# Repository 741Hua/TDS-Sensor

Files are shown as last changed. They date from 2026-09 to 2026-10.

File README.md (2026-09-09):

# TDS-Sensor
The industrial Total Dissolved Solids (TDS) sensor market currently sells sensors as a two part solution: an Electrical Conductivity (EC) sensor probe and a separate box with the digitization hardware. Introducing, an all-in-one enclosure, plug and play, industrial TDS sensor intended for use in food &amp; beverage manufacturing facilities.

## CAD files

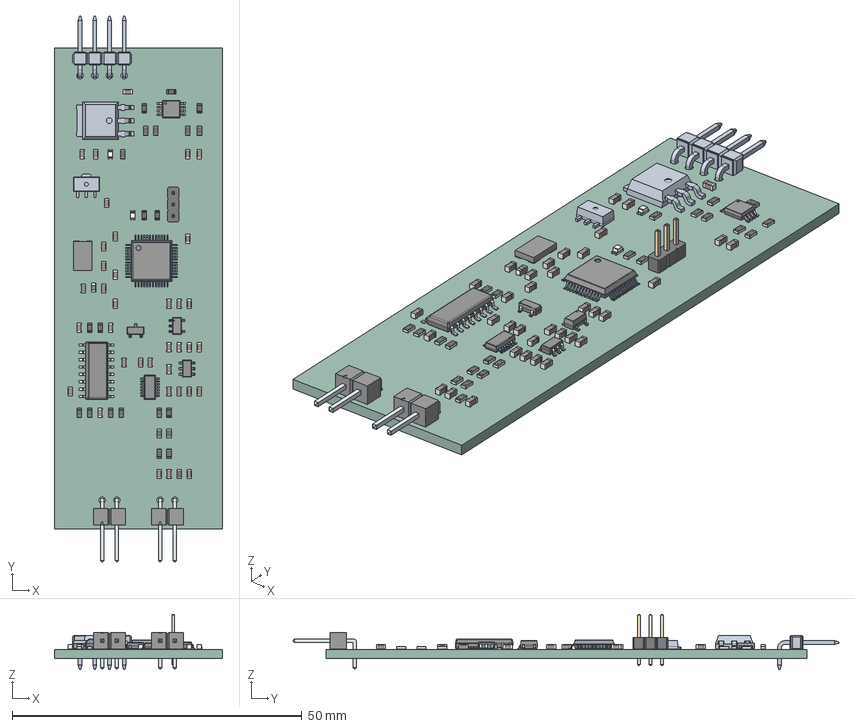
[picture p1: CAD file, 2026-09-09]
Hardware/TDS_Sensor.step
29.0 x 94.2 x 9.53 mm
R_0603_1608Metric x 23
C_0603_1608Metric x 36
PinHeader_1x03_P2.00mm_Vertical
TDS_Sensor 1.18.1
LTST-C190GKT x 2
Pins
BODY-SO
LEAD-SO x 16
PIN1-ID
PinsArrayL
PinsArrayR
LeadsArray x 2
PinsArrayLR x 2
PinsArrayTB
BAT54_R1_00001
BLM18BD121SH1D
BODY-TSSOP
LEAD-TSSOP x 14
TDS_Sensor 1.61.1
BODY-SOT
LEAD-SOT x 6
TDS_Sensor_PCB

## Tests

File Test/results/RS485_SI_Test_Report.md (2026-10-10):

# Hardware Bring‑Up Test Report 
**Document ID:** TDS-DTR-002 
**Revision:** 1.0  
**Author:** Jairo Huaylinos  
**Date:** 2026‑10-10

---

# Table of Contents
1. Introduction  
2. Unit Under Test  
3. Equipment Required  
4. Test Plan Overview  
5. Test Procedures 
6. References 

---

# 1. Introduction
This document defines the Modbus over RS-485 half duplex Signal Integrity (SI) testing for the All-In-One STM32‑based Total Dissolved Solids (TDS) sensor PCB. It outlines the Unit Under Test (UUT), required test equipment, describes the test stages, and provides step‑by‑step procedures with clear success criteria.

Goal: Verify reliable Modbus RTU communication over RS‑485 half‑duplex on the prototype PCB.
Scope: Protocol‑level timing and error‑free communication. Along with basic RS‑485 electrical sanity checks.

Regulatory and formal RS‑485 electrical and commercial industrial compliance (TIA‑485, FCC Part 15, UL 61010‑1, IEC 61326‑1) are out of scope for this prototype phase. Furthermore, the TIA‑485‑A standard does not specify rise time, fall time, or jitter requirements for RS‑485 drivers.

---

# 2. Unit Under Test (UUT)

The UUT is a custom STM32‑based TDS sensor PCB, serial number 2, paired with an electrical conductivity (EC) sensor probe. The board uses an STM32F103C8T6 microcontroller with a user LED on PC13 and includes an onboard RS‑485 transceiver (PN MAX485CUA+T) for the electrical interface for Modbus protocol communication. The analog front end is an AC‑excitation EC measurement circuit designed to output a DC voltage based on the conductivity through the external EC probe. Power is supplied through a 12 V input and regulated down to 5 V, 3.3 V, 3 V, and −3 V rails.

---

# 3. Equipment Required

| Name | Part Number | Description |
|---|---|---|
| ST‑Link Programmer | ST‑LINK/V2 | SWD programmer/debugger with 3.3 V supply |
| Personal Computer | N/A | Any Desktop PC or laptop |
| 12V Power Supply | N/A | 12 V DC Wall Adapter with modified leads |
| Oscilloscope | SDS 1202X-E | Siglent 200 MHz 1Gsa/s Digital Storage Oscilloscope |
| Digital Multimeter | DM6000AR | AstroAI True-RMS DMM, 6000 Counts |
| Blink Firmware | N/A | Toggles PC13 LED for basic MCU verification |
| Modbus Dummy Slave Firmware | N/A | Sends fixed Modbus FC04 response frames for RS‑485 validation |
| ADC + Modbus Firmware | N/A | Reads ADC and reports voltage via Modbus |
| ModbusTool SW |  N/A | Modbus Master tool to poll UUT. https://github.com/ClassicDIY/ModbusTool.git |
| USB - RS485 Converter | N/A | CERRXIAN 1FT RS485 to USB Terminal Converter Serial Port Cable |

---

# 4. Test Plan Overview

The RS485 Signal Integrity Test Plan covers 3 baud rates: 1200, 9600, 19200 Bd. For each of those rates, the following are verified:
- Successful transmission and reception of Modbus RTU messages.
- Device UART message frames are transmitted with less than 1.5 character times spacing. 1 character is defined as one full UART frame. 1 character is 11 bits (1 start bit, 8 bits for data, 1 parity bit, and 1 stop bit)
- Device transmission baud rate accuracy is within 1%.
- RS-485 logic voltage level differential between A and B should be between +-1.5V to +-6V

Each stage includes structured procedures with defined success criteria.

Out of scope:
- Recepetion baud rate tolerance of up to 2%. -> do not have tools to test this. this is more of a software capability.
- Response to both unicast and broadcast messages.
- Even Parity testing is not included since test plan is hardware centric, not protocol centric.

---

# 5. Test Procedures

---

## 5.1 ST‑Link Power‑Up Procedure

<p align="center">
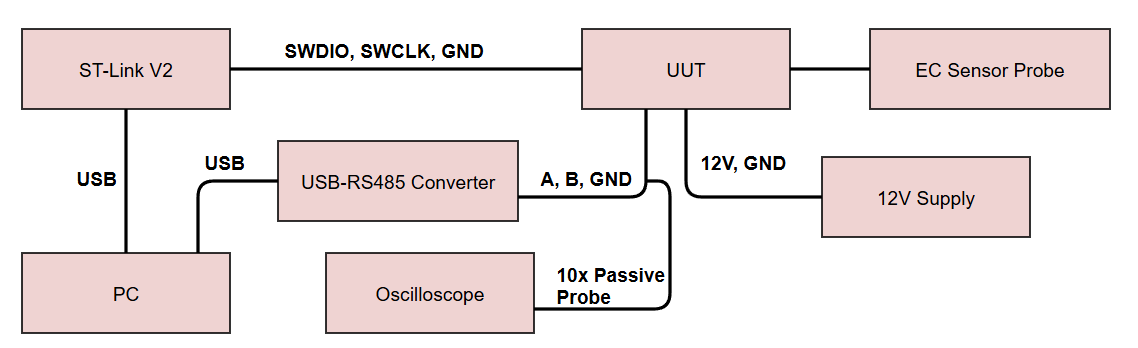
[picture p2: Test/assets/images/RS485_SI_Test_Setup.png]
Test Setup
  
  <br>
  <em>Figure 1: RS485 SI Test Setup</em>
</p>

<p>&nbsp;</p>

| Step # | Description | Success Criteria | P/F |
|---|---|---|-----|
| 1 | Connect the oscilloscope probes to the RS485 A (CH1) and B (CH2) output wires on the TDS sensor board | Probe is connected to A and B lines with appropriate ground reference | ✅ |
| 2 | Connect ST-Link SWCLK, SWDIO, and GND pins to the UUT on connector J2. Disconnect 3.3V pin | Board remains unpowered until 12V is applied | ✅ |
| 3 | Connect ST-Link SWCLK, SWDIO, and GND pins to the UUT on connector J2. Do not conect the 3.3V pin | Board remains unpowered until 12V is applied | ✅ |
| 4 | Connect the USB-RS485 Converter A, B, and GND rails to the UUT on connector J4. Connect the USB interface end to your PC. | Board remains unpowered until 12V is applied | ✅ |
| 5 | Flash Modbus RTU slave driver code with a 9600 baud rate (use a release build, not debug build). | Release build is successfully flashed to the board successfully with no errors | ✅ |
| 6 | Open the Modbus Master SW tool on your PC. Connect to the corresponding COM port with Baud=9600, Parity = None, Data Bits = 8, and Stop Bits = 1, Slave ID = 1. These settings should match you UART settings on the UUT's MCU. | Log shows "Connected using RTU to COMX", Stable connection. | ✅ |
| 7 | Select "read input register" in functions and set Poll to 4000 and check the box to activate polling. Set Start Address to 0. Set Size to 1. Click Apply button| Log shows "Read succeeded: Function Code: 4." | ✅ |
| 8 | Set oscilloscope to 2V/Div, 1ms/Div, trigger level to 2.5V, rising edge on CH2. Setup for normal capture, with 12ms holdoff. Press Stop on the second frame to display. | Oscilloscope captures modbus response frame from the TDS module and not master transmit frame. Verify bits.| ✅ |
| 9 | Measure the spacing between UART frames (10-bit Modbus Characters) | spacing between character frames are less than 1.5 characters long | ✅ |
| 10 | Measure baud rate | Measured Baud Rate is between 9504 and 9696 | ✅<sup>1</sup> |
| 11 | Measure the RS-485 voltage levels | voltage driver differential should be between +-1.5V to +-6V | ✅<sup>1</sup> |
| 12 | Measure the common mode voltage | Common Mode Voltage between -7V to +12V | ✅<sup>1</sup> |
| 13 | Flash Modbus RTU slave driver code with a 19200 baud rate (use a release build, not debug build). | Release build is successfully flashed to the board successfully with no errors | ✅ |
| 14 | Open the Modbus Master SW tool on your PC. Connect to the corresponding COM port with Baud=19200, Parity = None, Data Bits = 8, and Stop Bits = 1, Slave ID = 1. These settings should match you UART settings on the UUT's MCU. | Log shows "Connected using RTU to COMX", Stable connection. | ✅ |
| 15 | Select "read input register" in functions and set Poll to 1000 and check the box to activate polling. Set Start Address to 0. Set Size to 1. Click Apply button| Log shows "Read succeeded: Function Code: 4." | ✅ |
| 16 | Set oscilloscope to 2V/Div, 500us/Div, trigger level to 2.5V, rising edge on CH2. Setup for normal capture, with 8ms holdoff. Press Stop on the second frame to display. | Oscilloscope captures modbus response frame from the TDS module and not master transmit frame. Verify bits.| ✅ |
| 17 | Measure the spacing between UART frames (10-bit Modbus Characters) | spacing between character frames are less than 1.5 characters long | ✅ |
| 18 | Measure baud rate | Measured Baud Rate is between 19008 and 19392 | ✅<sup>1</sup> |
| 19 | Measure the RS-485 voltage levels | voltage driver differential should be between +-1.5V to +-6V | ✅<sup>1</sup> |
| 20 | Measure the common mode voltage | Common Mode Voltage between -7V to +12V | ✅<sup>1</sup> |
| 21 | Flash Modbus RTU slave driver code with a 1200 baud rate (use a release build, not debug build). | Release build is successfully flashed to the board successfully with no errors | ✅ |
| 22 | Open the Modbus Master SW tool on your PC. Connect to the corresponding COM port with Baud=1200, Parity = None, Data Bits = 8, and Stop Bits = 1, Slave ID = 1. These settings should match you UART settings on the UUT's MCU. | Log shows "Connected using RTU to COMX", Stable connection. | ✅ |
| 23 | Select "read input register" in functions and set Poll to 1000 and check the box to activate polling. Set Start Address to 0. Set Size to 1. Click Apply button| Log shows "Read succeeded: Function Code: 4." | ✅ |
| 24 | Set oscilloscope to 2V/Div, 5ms/Div, trigger level to 2.5V, rising edge on CH2. Setup for normal capture, with 70ms holdoff. Press Stop on the second frame to display. | Oscilloscope captures modbus response frame from the TDS module and not master transmit frame. Verify bits.| ✅ |
| 25 | Measure the spacing between UART frames (10-bit Modbus Characters) | spacing between character frames are less than 1.5 characters long | ✅ |
| 26 | Measure baud rate | Measured Baud Rate is between 1188 and 1212 | ✅<sup>1</sup> |
| 27 | Measure the RS-485 voltage levels | voltage driver differential should be between +-1.5V to +-6V | ✅<sup>1</sup> |
| 28 | Measure the common mode voltage | Common Mode Voltage between -7V to +12V | ✅<sup>1</sup> |

### Notes

1. The measured baud rate, A-B differential voltage, and common mode voltage values are recorded below for each tested communication rate.

| Baud Rate | Measured Baud Rate | A-B Voltage Differential | Common Mode Voltage |
|---|---|---|---|
| 9600 | 9615 | ~2.78V | ~2.14V |
| 19200 | 19160 | ~2.76V | ~2.145V |
| 1200 | 1198 | ~2.78V | ~2.145 |

<p align="center">
  <em>Figure 2: Measured Values from Test</em>
</p>

---

# 6. References

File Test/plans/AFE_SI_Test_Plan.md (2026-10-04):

# Hardware Bring‑Up Test Plan & Procedures  
**Document ID:** TDS-DTP-004 
**Revision:** 1.0  
**Author:** Jairo Huaylinos  
**Date:** 2026‑10-04

---

# Table of Contents
1. Introduction  
2. Unit Under Test  
3. Equipment Required  
4. Test Plan Overview  
5. Test Procedures  
6. References

---

# 1. Introduction
This document defines the Modbus over RS-485 half duplex Signal Integrity (SI) testing for the All-In-One STM32‑based Total Dissolved Solids (TDS) sensor PCB. It outlines the Unit Under Test (UUT), required test equipment, describes the test stages, and provides step‑by‑step procedures with clear success criteria.

Goal: Verify reliable Modbus RTU communication over RS‑485 half‑duplex on the prototype PCB.
Scope: Protocol‑level timing and error‑free communication. Along with basic RS‑485 electrical sanity checks.

Regulatory and formal RS‑485 electrical and commercial industrial compliance (TIA‑485, FCC Part 15, UL 61010‑1, IEC 61326‑1) are out of scope for this prototype phase. Furthermore, the TIA‑485‑A standard does not specify rise time, fall time, or jitter requirements for RS‑485 drivers.

---

# 2. Unit Under Test (UUT)

The UUT is a custom STM32‑based TDS sensor PCB, serial number 2, paired with an electrical conductivity (EC) sensor probe. The board uses an STM32F103C8T6 microcontroller with a user LED on PC13 and includes an onboard RS‑485 transceiver (PN MAX485CUA+T) for the electrical interface for Modbus protocol communication. The analog front end is an AC‑excitation EC measurement circuit designed to output a DC voltage based on the conductivity through the external EC probe. Power is supplied through a 12 V input and regulated down to 5 V, 3.3 V, 3 V, and −3 V rails.

---

# 3. Equipment Required

| Name | Part Number | Description |
|---|---|---|
|  |  |  |
|  |  |  |
|  |  |  |
|  |  |  |
|  |  |  |
|  |  |  |
|  |  |  |
|  |  |  |
|  |  |  |
|  |  |  |

---

# 4. Test Plan Overview

The hardware bring‑up consists of four main stages:

1. **Packet transmission**  
   Verifies MCU boot, clock operation, GPIO functionality, and basic power behavior using the debugger’s 3.3 V supply.

2. **Signal Rise & Fall Times**  
   The manufacturer for the MAX485CUA+T characterizes drive rise and fall times (t<sub>R</sub>, t<sub>F</sub>) as (MIN: 3ns, TYP: 15ns, MAX: 40ns) and maximum data rate f<sub>MAX</sub> as 2.5 Mbps.

Each stage includes structured procedures with defined success criteria.

Modbus communication at different baud rates. Capture log. Use representative cable lengths.

Notes for what the test should include:
   - that the device responds to both broadcast and unicast requests from the master. (Using both Even parity (required) and no parity (recommended))
   - 3.5 character spacing betweem message frames
   - try sending modbbus frames at the maximum size of 256 bytes
   - slave transmit messsage frame shoud have less than 1.5 char time spacing between 2 characters. Verify this.
   - Does my modbus slave driver code include interrupts for t1.5 and t3.5? does it monitor this? Consequently these two timers must be strictly respected when the baud rate is equal or lower than 19200 Bps
   - Typical buad rate for RS485 is 9600. 9600 bps and 19.2 Kbps are required. Must test these 2 baud rates, also test a lower baud rate of 1200. There is no minimum but this is the typical minimum baud rate in modern systems.
   - Transmit baud rate accuracy must be within 1%. Reception baud rate tolerance: must accept up to 2% error. Not sure how you'd test the reception tolerance. Where does this 1% requirement come?

Ok so test goals (hardware centric only)
- Device can recieve and transmit at 9600 bps, 19200 bps, and 1200 bps.
- Device RTU message frames must be transmitted with less than 1.5 character times spacing.
- Device transmission baud rate accuracy is within 1%.
- RS-485 voltage levels are correct.
- Less than 200mV magnitude difference between RS485 A-B vs B-A signal.

Even parity testing is not necessary here, goal is hardware centric.

1.5 character spacing: 1 character is defined as one full UART frame. 1 character is 11 bits (1 start bit, 8 bits for data, 1 parity bit, and 1 stop bit).

Out of scope:
- Recepetion baud rate tolerance of up to 2%. -> do not have tools to test this. this is more of a software capability.
- Response to both unicast and broadcast messages.
- 

---

# 5. Test Procedures

---

## 5.1 ST‑Link Power‑Up Procedure

<p align="center">
  Test Setup
  <br>
  <em>Figure 1: RS485 SI Test Setup</em>
</p>

<p>&nbsp;</p>

| Step # | Description | Success Criteria | P/F |
|---|---|---|-----|
| 1 |  |  |  |
| 2 |  |  |  |
| 3 |  |  |  |
| 4 |  |  |  |
| 5 |  |  |  |
| 6 |  |  |  |
| 7 |  |  |  |
| 8 |  |  |  |
| 9 |  |  |  |
| 10 |  |  |  |
| 11 |  |  |  |
| 12 |  |  |  |
| 13 |  |  |  |
| 14 |  |  |  |
| 15 |  |  |  |
| 16 |  |  |  |
| 17 |  |  |  |
| 18 |  |  |  |
| 19 |  |  |  |
| 20 |  |  |  |
| 21 |  |  |  |
| 22 |  |  |  |
| 23 |  |  |  |
| 24 |  |  |  |
| 25 |  |  |  |
| 26 |  |  |  |
| 27 |  |  |  |
| 28 |  |  |  |

### Notes

---

## 5.4 Analog Front End + ADC Verification Procedure

<p align="center">
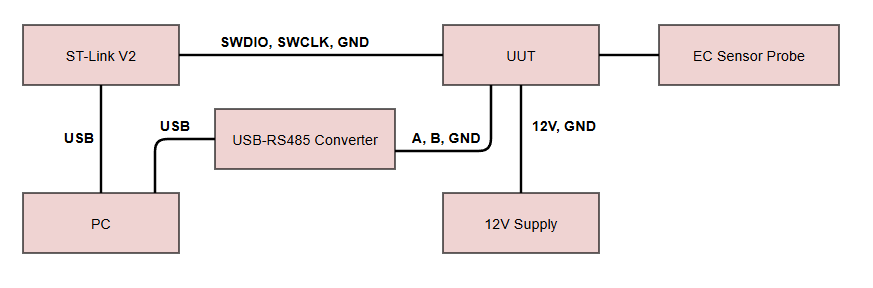
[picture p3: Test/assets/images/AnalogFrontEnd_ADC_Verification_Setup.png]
Test Setup
  
  <br>
  <em>Figure 4: Analog Front End + ADC Verification Test Setup</em>
</p>

<p>&nbsp;</p>

| Step # | Description | Success Criteria | P/F |
|---|---|---|-----|
| 1 |  |  |  |
| 2 |  |  |  |
| 3 |  |  |  |
| 4 |  |  |  |
| 5 |  |  |  |
| 6 |  |  |  |
| 7 |  |  |  |
| 8 |  |  |  |
| 9 |  |  |  |
| 10 |  |  |  |
| 11 |  |  |  |
| 12 |  |  |  |

### Notes

---

# 6. References

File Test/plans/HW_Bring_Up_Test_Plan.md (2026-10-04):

# Hardware Bring‑Up Test Plan & Procedures  
**Document ID:** TDS-DTP-001
**Revision:** 1.0  
**Author:** Jairo Huaylinos
**Date:** 2026‑09‑12  

---

# Table of Contents
1. Introduction  
2. Unit Under Test  
3. Equipment Required  
4. Test Plan Overview  
5. Test Procedures  
   - 5.1 ST‑Link Power‑Up & Blink 
   - 5.2 External 12 V Power‑Up  & Blink
   - 5.3 RS‑485 Modbus Communication  
   - 5.4 Analog Front End + ADC Verification  
6. References

---

# 1. Introduction
This document defines the hardware bring‑up plan and procedures for the All-In-One STM32‑based Total Dissolved Solids (TDS) sensor PCB. It outlines the Unit Under Test (UUT), required test equipment, describes the test stages, and provides step‑by‑step procedures with clear success criteria.

---

# 2. Unit Under Test (UUT)

The UUT is a custom STM32‑based TDS sensor PCB, serial number 2, paired with an electrical conductivity (EC) sensor probe. The board uses an STM32F103C8T6 microcontroller with a user LED on PC13 and includes an onboard RS‑485 transceiver (PN MAX485CUA+T) for the electrical interface for Modbus protocol communication. The analog front end is an AC‑excitation EC measurement circuit designed to output a DC voltage based on the conductivity through the external EC probe. Power is supplied through a 12 V input and regulated down to 5 V, 3.3 V, 3 V, and −3 V rails. This bring‑up verifies that the MCU initializes correctly, the power rails are stable, the RS‑485 interface communicates reliably, and the analog front end produces valid ADC readings.

---

# 3. Equipment Required

| Name | Part Number | Description |
|---|---|---|
| ST‑Link Programmer | ST‑LINK/V2 | SWD programmer/debugger with 3.3 V supply |
| Personal Computer | N/A | Any Desktop PC or laptop |
| 12V Power Supply | N/A | 12 V DC Wall Adapter with modified leads |
| Oscilloscope | SDS 1202X-E | Siglent 200 MHz 1Gsa/s Digital Storage Oscilloscope |
| Digital Multimeter | DM6000AR | AstroAI True-RMS DMM, 6000 Counts |
| Blink Firmware | N/A | Toggles PC13 LED for basic MCU verification |
| Modbus Dummy Slave Firmware | N/A | Sends fixed Modbus FC04 response frames for RS‑485 validation |
| ADC + Modbus Firmware | N/A | Reads ADC and reports voltage via Modbus |
| ModbusTool SW |  N/A | Modbus Master tool to poll UUT. https://github.com/ClassicDIY/ModbusTool.git |
| USB - RS485 Converter | N/A | CERRXIAN 1FT RS485 to USB Terminal Converter Serial Port Cable |

---

# 4. Test Plan Overview

The hardware bring‑up consists of four main stages:

1. **ST‑Link Power‑Up & Blink**  
   Verifies MCU boot, clock operation, GPIO functionality, and basic power behavior using the debugger’s 3.3 V supply.

2. **External 12 V Power‑Up & Blink**  
   Validates the full power chain (12 V ⇒ 5 V ⇒ 3.3 V ⇒ 3V ⇒ -3V) and confirms the board operates correctly from its intended supply.

3. **RS‑485 Modbus Communication**  
   Confirms UART configuration, RS‑485 transceiver operation, and basic Modbus frame reception and transmission.

4. **Analog Front End + ADC Verification**  
   Checks the analog signal path, ADC conversion accuracy, and Modbus‑reported voltage values.

Each stage includes structured procedures with defined success criteria.

---

# 5. Test Procedures

---

## 5.1 ST‑Link Power‑Up Procedure

<p align="center">
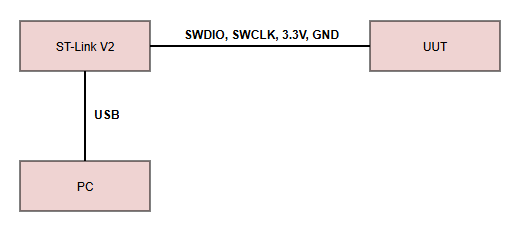
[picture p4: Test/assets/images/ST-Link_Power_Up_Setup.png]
Test Setup
  
  <br>
  <em>Figure 1: ST-Link Power Up Test Setup</em>
</p>

<p>&nbsp;</p>

| Step # | Description | Success Criteria | P/F |
|---|---|---|-----|
| 1 | Connect ST‑Link SWCLK, SWDIO 3.3 V, and GND pins to the UUT on connector J2| ST‑Link connects to MCU without errors |  |
| 2 | Measure 3.3V rail with DMM at C4 | Voltage is within 3.2–3.4V |  |
| 3 | Measure 3V rail with DMM at C18 | Voltage is within 2.9–3.1V |  |
| 4 | Measure -3V rail with DMM at C20 | Voltage is within (-3.1)–(-2.9)V |  |
| 5 | Flash blink firmware (PC13 LED) | Firmware loads successfully |  |
| 6 | Observe PC13 LED | LED blinks at a rate of approx. 0.5s |  |

### Notes

---

## 5.2 External 12 V Power‑Up Procedure

<p align="center">
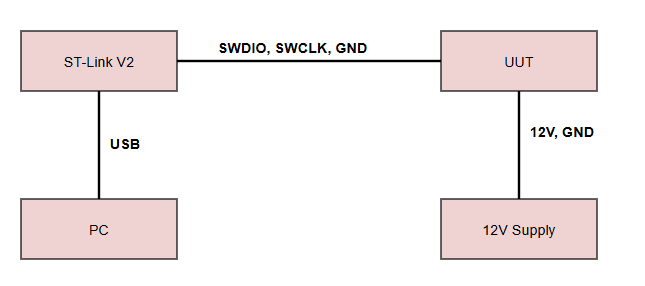
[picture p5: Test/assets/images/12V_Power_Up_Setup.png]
Test Setup
  
  <br>
  <em>Figure 2: External 12V Power-Up Test Setup</em>
</p>

<p>&nbsp;</p>

| Step # | Description | Success Criteria | P/F |
|---|---|---|-----|
| 1 | Connect ST-Link SWCLK, SWDIO, and GND pins to the UUT on connector J2. Disconnect 3.3V pin | Board remains unpowered until 12V is applied |  |
| 2 | Connect the 12V Power Supply power and ground to connector J4 on the UUT| Power supply power and ground is physically connected to J4 pin 1 (P_IN) and pin 4 (GND)|  |
| 3 | Measure 12V rail with the DMM | Voltage is within 11.9-12.1V |  |
| 4 | Measure 5V rail with the DMM| Votlage is within 4.9–5.1V |  |
| 5 | Measure 3.3V rail with the DMM| Voltage is within 3.2–3.4V |  |
| 6 | Measure 3V rail with DMM at C18 | Voltage is within 2.9–3.1V |  |
| 7 | Measure -3V rail with DMM at C20 | Voltage is within (-3.1)–(-2.9)V |  |
| 8 | Flash blink firmware (PC13 LED) | Firmware loads successfully |  |
| 9 | Observe PC13 LED | LED blinks at a rate of approx. 0.5s |  |

### Notes

---

## 5.3 RS‑485 Modbus Communication Procedure

<p align="center">
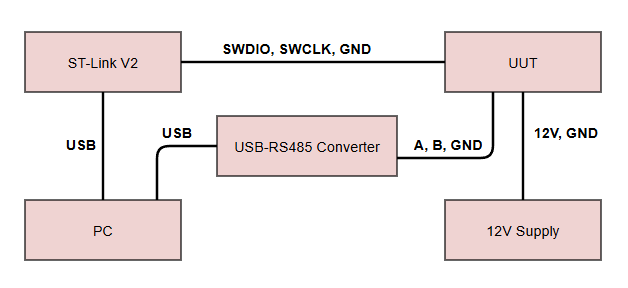
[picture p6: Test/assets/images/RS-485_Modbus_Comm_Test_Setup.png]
Test Setup
  
  <br>
  <em>Figure 3: RS-485 Modbus Communication Test Setup</em>
</p>

<p>&nbsp;</p>

| Step # | Description | Success Criteria | P/F |
|---|---|---|-----|
| 1 | Connect ST-Link SWCLK, SWDIO, and GND pins to the UUT on connector J2. Do not conect the 3.3V pin | Board remains unpowered until 12V is applied |  |
| 2 | Connect the USB-RS485 Converter A, B, and GND rails to the UUT on connector J4. Connect the USB interface end to your PC. | Board remains unpowered until 12V is applied |  |
| 3 | Connect the 12V Power Supply power and ground to connector J4 on the UUT| Power supply power and ground is physically connected to J4 pin 1 (P_IN) and pin 4 (GND)|  |
| 4 | Flash Modbus dummy slave RX/TX firmware | Firmware loads successfully |  |
| 5 | Open the Modbus Master SW tool on your PC. Connect to the corresponding COM port with Baud=9600, Parity = None, Data Bits = 8, and Stop Bits = 1, Slave ID = 1. These settings should match you UART settings on the UUT's MCU. | Log shows "Connected using RTU to COMX", Stable connection. |  |
| 6 | Select "read input register" in functions and set Poll to 1000 and check the box to activate polling. Set Start Address to 0. Set Size to 1. Click Apply button| Log shows "Read succeeded: Function Code: 4." |  |
| 7 | Monitor Modbus TX and RX frames on the Log| Log shows "TX: 01 04 00 00 00 01 31 ca" and "RX: 01 04 02 XX XX XX XX" |  |
| 8 | Verify RX payload and CRC | For example, if the UUT's input register at address 1 is set to 2, then the log should show "RX: 01 04 02 00 02 38 f1". If you have a different payload configured validate the correct payload and CRC bytes using https://valtoris.com/tools/modbus-rtu-crc-16-calculator-hex-checksum-debugging-tool/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 |  |

### Notes

---

## 5.4 Analog Front End + ADC Verification Procedure

<p align="center">
  Test Setup
  <br>
  <em>Figure 4: Analog Front End + ADC Verification Test Setup</em>
</p>

<p>&nbsp;</p>

| Step # | Description | Success Criteria | P/F |
|---|---|---|-----|
| 1 | Connect ST-Link SWCLK, SWDIO, and GND pins to the UUT on connector J2. Do not conect the 3.3V pin | Board remains unpowered until 12V is applied |  |
| 2 | Connect the USB-RS485 Converter A, B, and GND rails to the UUT on connector J4. Connect the USB interface end to your PC. | Board remains unpowered until 12V is applied |  |
| 3 | Connect  the EC sensor probe to connector J3 on the UUT | EC sensor probe is connected to the UUT |  |
| 4 | Connect the 12V Power Supply power and ground to connector J4 on the UUT| Power supply power and ground is physically connected to J4 pin 1 (P_IN) and pin 4 (GND)|  |
| 5 | Measure the 3.3V supply voltage with the DMM at C6 (close to the MCU) and record it (V<sub>in</sub>). | 3.2V-3.4V is measured and recorded | |
| 6 | Calculate the ADC to Voltage conversion factor using K = 10<sup>4</sup> x 4095/V<sub>in</sub> | Conversion factor is about equal to the ideal conversion factor of 10<sup>4</sup> x 3.3V/4095 = 8.0586 |  |
| 7 | Update the ADC + Modbus Firmware with your conversion factor in: `v_reading = sensor_reading * 8.105f;` | Firmware builds with no errors |  | 
| 8 | Flash ADC + Modbus firmware | Firmware loads successfully |  |
| 9 | Dip the EC sensor probe into a water solution. | Only the waterproof EC sensor probe is in water solution and water is not in contact with the rest of the UUT. |  |
| 10 | Measure ADC input voltage with DMM at D8 and record it.| Stable reading; no unexpected fluctuations |  |
| 11 | Read Modbus‑reported voltage (represented in hex value, with decimal converter number in units of 10<sup>-4</sup> V) | Log shows "RX: 01 04 02 XX XX YY YY", with XX XX being the voltage value. |  |
| 12 | Compare DMM vs Modbus values | Values are reasonably close (pre‑calibration tolerance) |  |

### Notes

---

# 6. References

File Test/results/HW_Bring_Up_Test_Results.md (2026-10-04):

# Hardware Bring‑Up Test Results
**Document ID:** TDS-Results-001
**Revision:** 1.0  
**Author:** Jairo Huaylinos
**Date:** 2026‑09‑13 

---

# Table of Contents
1. Introduction  
2. Unit Under Test  
3. Equipment Required  
4. Test Plan Overview  
5. Test Results  
   - 5.1 ST‑Link Power‑Up & Blink 
   - 5.2 External 12 V Power‑Up  & Blink
   - 5.3 RS‑485 Modbus Communication  
   - 5.4 Analog Front End + ADC Verification  

---

# 1. Introduction
This document contains the hardware bring‑up test results for the All-In-One STM32‑based Total Dissolved Solids (TDS) sensor PCB. It outlines the pass and fails per result, along with observations logged in the notes section. Failures are documented in the notes section of every test stage with a reference to the corresponding Root Cause Analysis and solution.

---

# 2. Unit Under Test (UUT)

The UUT is a custom STM32‑based TDS sensor PCB, serial number 2, paired with an electrical conductivity (EC) sensor probe. The board uses an STM32F103C8T6 microcontroller with a user LED on PC13 and includes an onboard RS‑485 transceiver (PN MAX485CUA+T) for the electrical interface for Modbus protocol communication. The analog front end is an AC‑excitation EC measurement circuit designed to output a DC voltage based on the conductivity through the external EC probe. Power is supplied through a 12 V input and regulated down to 5 V, 3.3 V, 3 V, and −3 V rails. This bring‑up verifies that the MCU initializes correctly, the power rails are stable, the RS‑485 interface communicates reliably, and the analog front end produces valid ADC readings.

---

# 3. Equipment Required

| Name | Part Number | Description |
|---|---|---|
| ST‑Link Programmer | ST‑LINK/V2 | SWD programmer/debugger with 3.3 V supply |
| Personal Computer | N/A | Any Desktop PC or laptop |
| 12V Power Supply | N/A | 12 V DC Wall Adapter with modified leads |
| Oscilloscope | SDS 1202X-E | Siglent 200 MHz 1Gsa/s Digital Storage Oscilloscope |
| Digital Multimeter | DM6000AR | AstroAI True-RMS DMM, 6000 Counts |
| Blink Firmware | N/A | Toggles PC13 LED for basic MCU verification |
| Modbus Dummy Slave Firmware | N/A | Sends fixed Modbus FC04 response frames for RS‑485 validation |
| ADC + Modbus Firmware | N/A | Reads ADC and reports voltage via Modbus |
| ModbusTool SW |  N/A | Modbus Master tool to poll UUT. https://github.com/ClassicDIY/ModbusTool.git |
| USB - RS485 Converter | N/A | CERRXIAN 1FT RS485 to USB Terminal Converter Serial Port Cable |

---

# 4. Test Plan Overview

The hardware bring‑up consists of four main stages:

1. **ST‑Link Power‑Up & Blink**  
   Verifies MCU boot, clock operation, GPIO functionality, and basic power behavior using the debugger’s 3.3 V supply.

2. **External 12 V Power‑Up & Blink**  
   Validates the full power chain (12 V ⇒ 5 V ⇒ 3.3 V ⇒ 3V ⇒ -3V) and confirms the board operates correctly from its intended supply.

3. **RS‑485 Modbus Communication**  
   Confirms UART configuration, RS‑485 transceiver operation, and basic Modbus frame reception and transmission.

4. **Analog Front End + ADC Verification**  
   Checks the analog signal path, ADC conversion accuracy, and Modbus‑reported voltage values.

Each stage includes structured results with defined success and failure notes.

---

# 5. Test Results

---

## 5.1 ST‑Link Power‑Up Result

<p align="center">
  Test Setup
  <br>
  <em>Figure 1: ST-Link Power Up Test Setup</em>
</p>

<p>&nbsp;</p>

| Step # | Description | Success Criteria | P/F | P/F<sup>2</sup> |
|---|---|---|-----|---|
| 1 | Connect ST‑Link SWCLK, SWDIO 3.3 V, and GND pins to the UUT on connector J2| ST‑Link connects to MCU without errors | ✅ | ✅ |
| 2 | Measure 3.3V rail with DMM at C4 | Voltage is within 3.2–3.4V | ❌<sup>1</sup> | ✅ |
| 3 | Measure 3V rail with DMM at C18 | Voltage is within 2.9–3.1V | ❌<sup>1</sup> | ✅ |
| 4 | Measure -3V rail with DMM at C20 | Voltage is within (-3.1)–(-2.9)V | ❌<sup>1</sup> | ✅ |
| 5 | Flash blink firmware (PC13 LED) | Firmware loads successfully | ✅<sup>1</sup> | ✅ |
| 6 | Observe PC13 LED | LED blinks at a rate of approx. 0.5s | ✅<sup>1</sup> | ✅ |

### Notes
1. Significant voltage sag observed. Measured voltage at C4 was 2.4V. Despite this, firmware was still mistakenly flashed but loaded successfully and LED blinked at the appropriate rate, although dim. No damage to board observed. See RCA in [Reference 1](#reference-1).
2. "P/F 2" column are test results after Corrective Action in RCA in [Reference 1](#reference-1).

### Conclusion

---

## 5.2 External 12 V Power‑Up Result

<p align="center">
  Test Setup
  <br>
  <em>Figure 2: External 12V Power-Up Test Setup</em>
</p>

<p>&nbsp;</p>

| Step # | Description | Success Criteria | P/F<sup>1</sup> |
|---|---|---|-----|
| 1 | Connect ST-Link SWCLK, SWDIO, and GND pins to the UUT on connector J2. Disconnect 3.3V pin | Board remains unpowered until 12V is applied | ✅ |
| 2 | Connect the 12V Power Supply power and ground to connector J4 on the UUT| Power supply power and ground is physically connected to J4 pin 1 (P_IN) and pin 4 (GND)| ✅ |
| 3 | Measure 12V rail with the DMM | Voltage is within 11.9-12.1V | ✅ |
| 4 | Measure 5V rail with the DMM| Votlage is within 4.9–5.1V | ✅ |
| 5 | Measure 3.3V rail with the DMM| Voltage is within 3.2–3.4V | ✅ |
| 6 | Measure 3V rail with DMM at C18 | Voltage is within 2.9–3.1V | ✅ |
| 7 | Measure -3V rail with DMM at C20 | Voltage is within (-3.1)–(-2.9)V | ✅ |
| 8 | Flash blink firmware (PC13 LED) | Firmware loads successfully | ✅ |
| 8 | Observe PC13 LED | LED blinks at a rate of approx. 0.5s | ✅ |

### Notes
1. "P/F" column are test results after Corrective Action in RCA in [Reference 1](#reference-1).

---

## 5.3 RS‑485 Modbus Communication Result

<p align="center">
  Test Setup
  <br>
  <em>Figure 3: RS-485 Modbus Communication Test Setup</em>
</p>

<p>&nbsp;</p>

| Step # | Description | Success Criteria | P/F<sup>1</sup> |
|---|---|---|-----|
| 1 | Connect ST-Link SWCLK, SWDIO, and GND pins to the UUT on connector J2. Do not conect the 3.3V pin | Board remains unpowered until 12V is applied | ✅ |
| 2 | Connect the USB-RS485 Converter A, B, and GND rails to the UUT on connector J4. Connect the USB interface end to your PC. | Board remains unpowered until 12V is applied | ✅ |
| 3 | Connect the 12V Power Supply power and ground to connector J4 on the UUT| Power supply power and ground is physically connected to J4 pin 1 (P_IN) and pin 4 (GND)| ✅ |
| 4 | Flash Modbus dummy slave RX/TX firmware | Firmware loads successfully | ✅ |
| 5 | Open the Modbus Master SW tool on your PC. Connect to the corresponding COM port with Baud=9600, Parity = None, Data Bits = 8, and Stop Bits = 1, Slave ID = 1. These settings should match you UART settings on the UUT's MCU. | Log shows "Connected using RTU to COMX", Stable connection. | ✅<sup>2</sup> |
| 6 | Select "read input register" in functions and set Poll to 1000 and check the box to activate polling. Set Start Address to 0. Set Size to 1. Click Apply button| Log shows "Read succeeded: Function Code: 4." | ✅ |
| 7 | Monitor Modbus TX and RX frames on the Log| Log shows "TX: 01 04 00 00 00 01 31 ca" and "RX: 01 04 02 XX XX XX XX" | ✅<sup>3</sup> |
| 8 | Verify RX payload and CRC | For example, if the UUT's input register at address 1 is set to 2, then the log should show "RX: 01 04 02 00 02 38 f1". If you have a different payload configured validate the correct payload and CRC bytes using https://valtoris.com/tools/modbus-rtu-crc-16-calculator-hex-checksum-debugging-tool/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 | ✅ |

### Notes
1. "P/F" column are test results after Corrective Action in RCA in [Reference 1](#reference-1).
2. "Connected using RTU to COM3".
3. Log displayed receive message: "RX: 01 04 02 00 02 38 f1"
---

## 5.4 Analog Front End + ADC Verification Result

<p align="center">
  Test Setup
  <br>
  <em>Figure 4: Analog Front End + ADC Verification Test Setup</em>
</p>

<p>&nbsp;</p>

| Step # | Description | Success Criteria | P/F<sup>[1]</sup>| P/F<sup>[2]</sup>|
|---|---|---|-----|-----|
| 1 | Connect ST-Link SWCLK, SWDIO, and GND pins to the UUT on connector J2. Do not conect the 3.3V pin | Board remains unpowered until 12V is applied | ✅ |  |
| 2 | Connect the USB-RS485 Converter A, B, and GND rails to the UUT on connector J4. Connect the USB interface end to your PC. | Board remains unpowered until 12V is applied | ✅ |  |
| 3 | Connect  the EC sensor probe to connector J3 on the UUT | EC sensor probe is connected to the UUT | ✅ |  |
| 4 | Connect the 12V Power Supply power and ground to connector J4 on the UUT| Power supply power and ground is physically connected to J4 pin 1 (P_IN) and pin 4 (GND)| ✅ |  |
| 5 | Measure the 3.3V supply voltage with the DMM at C6 (close to the MCU) and record it (V<sub>in</sub>). | 3.2V-3.4V is measured and recorded | ✅ |  3.315V|
| 6 | Calculate the ADC to Voltage conversion factor using K = 10<sup>4</sup> x 4095/V<sub>in</sub> | Conversion factor is about equal to the ideal conversion factor of 10<sup>4</sup> x 3.3V/4095 = 8.0586 | ✅<sup>[3]</sup> |  |
| 7 | Update the ADC + Modbus Firmware with your conversion factor in: `v_reading = sensor_reading * 8.105f;` | Firmware builds with no errors | ✅ |  |
| 8 | Flash ADC + Modbus firmware | Firmware loads successfully | ✅ |  |
| 9 | Dip the EC sensor probe into a water solution. | Only the waterproof EC sensor probe is in water solution and water is not in contact with the rest of the UUT. | ✅ |  |
| 10 | Measure ADC input voltage with DMM at D8 and record it.| Stable reading; no unexpected fluctuations | ❌<sup>[4]</sup> | 2.264V |
| 11 | Read Modbus‑reported voltage (represented in hex value, with decimal converter number in units of 10<sup>-4</sup> V) | Log shows "RX: 01 04 02 XX XX YY YY", with XX XX being the voltage value. | ✅ | 2.2199V reported per ADC (56B7) (actual DMM 2.271V) 0.0511V deviation (on 1.5 clock cycle ADC sampling time). With a 28.5 cycle sampling time, we observed a reported 2.288V while the actual was 2.338V. (Not a fluke, ran this test twice same results, observed higher voltage with 28.5 clock cycles). ok with 71.5 clock cycles, we see reported 2.305V and 2.354V actual (0.049V deviation). Error deviation is fixed at 0.05V (due to conversion). However, voltage is increasing with higher clock cycles. with 239.5 cycle reported 2.3115V (2.361V actual)|
| 12 | Compare DMM vs Modbus values | Values are reasonably close (pre‑calibration tolerance) | ❌<sup>[4]</sup> |  |

### Notes
1. "P/F<sup>[1]</sup>" column are test results after Corrective Action in RCA in [Reference 1](#reference-1).
2. "P/F<sup>[2]</sup>" column are test results after Corrective Action in RCA in [Reference 2](#reference-2).
3. V<sub>in</sub> was 3.319V and conversion factor was 8.105.
4. Measured ADC voltage at D8 was -220mV. Modubs Voltage reading is 0V. Under normal operation, ADC voltage should never be below 0V. See RCA in [Reference 2](#reference-2).

---

# 6. References
##### Reference 1
[ST Link Power Up RCA](./RCA/ST_Link_Power_Up_RCA.md)
##### Reference 2
[AFE and ADC Verification RCA](./RCA/AFE_ADC_Verification_RCA.md)

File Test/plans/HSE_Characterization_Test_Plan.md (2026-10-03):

# HSE Characterization Test Plan & Procedures  
**Document ID:** TDS-DTP-003  
**Revision:** 1.0  
**Author:** Jairo Huaylinos  
**Date:** 2026‑10-03 

---

# Table of Contents
1. Introduction  
2. Unit Under Test  
3. Equipment Required  
4. Test Procedures  
   - 4.1  

---

# 1. Introduction
This document defines the High Speed External Crystal (HSE) Oscillator characterization testing for the All-In-One STM32‑based Total Dissolved Solids (TDS) sensor PCB. It outlines the Unit Under Test (UUT), required test equipment, describes the test stages, and provides step‑by‑step procedures with clear success criteria.

Goal: Verify that the HSE crystal oscillator oscillates at 8MHz.
Scope: The signal integrity test covers 8 MHz High‑Speed External (HSE) crystal oscillator on the STM32‑based TDS sensor PCB. It verifies that the HSE oscillator:
   - Starts reliably under nominal operating conditions
   - Oscillates at the correct frequency within the specified tolerance

The scope is limited to bench‑level frequency characterization of the HSE oscillator on the prototype PCB and does not include EMC, safety, or long‑term reliability testing. Startup time measurement is out of scope due to lack of lab equipment.

<p align="center">
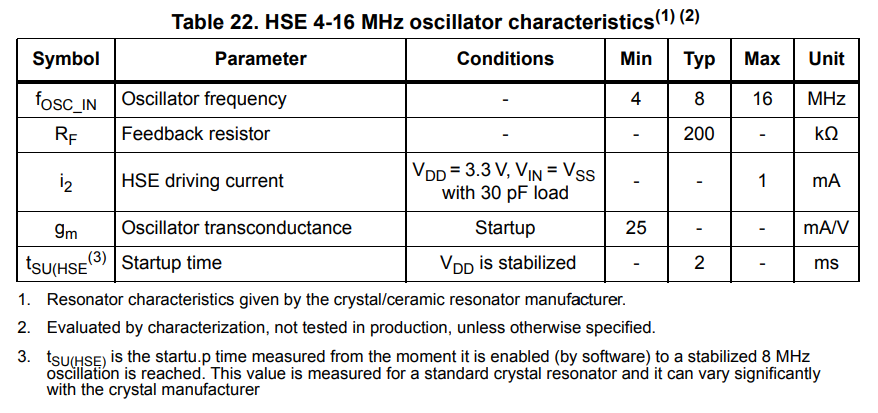
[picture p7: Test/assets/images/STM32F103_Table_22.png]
STM32 Datasheet HSE characteristics
  
  <br>
  <em>Figure 1: STM32F103 Datasheet HSE crystal oscillator characteristics</em>
</p>

<p>&nbsp;</p>

---

# 2. Unit Under Test (UUT)

The UUT is a custom STM32‑based TDS sensor PCB, serial number 2, paired with an electrical conductivity (EC) sensor probe. The board uses an STM32F103C8T6 microcontroller with a user LED on PC13 and includes an onboard RS‑485 transceiver (PN MAX485CUA+T) for the electrical interface for Modbus protocol communication. The analog front end is an AC‑excitation EC measurement circuit designed to output a DC voltage based on the conductivity through the external EC probe. Power is supplied through a 12 V input and regulated down to 5 V, 3.3 V, 3 V, and −3 V rails.

---

# 3. Equipment Required

| Name | Part Number | Description |
|---|---|---|
| ST‑Link Programmer | ST‑LINK/V2 | SWD programmer/debugger with 3.3 V supply |
| Personal Computer | N/A | Any Desktop PC or laptop |
| 12V Power Supply | N/A | 12 V DC Wall Adapter with modified leads |
| Oscilloscope | SDS 1202X-E | Siglent 200 MHz 1Gsa/s Digital Storage Oscilloscope |
| Digital Multimeter | DM6000AR | AstroAI True-RMS DMM, 6000 Counts |
| Blink Firmware | N/A | Toggles PC13 LED for basic MCU verification |
| Modbus Dummy Slave Firmware | N/A | Sends fixed Modbus FC04 response frames for RS‑485 validation |
| ADC + Modbus Firmware | N/A | Reads ADC and reports voltage via Modbus |
| ModbusTool SW |  N/A | Modbus Master tool to poll UUT. https://github.com/ClassicDIY/ModbusTool.git |
| USB - RS485 Converter | N/A | CERRXIAN 1FT RS485 to USB Terminal Converter Serial Port Cable |

---

# 4. Test Procedures

---

## 4.1 HSE Characteristics Test Procedure

<p align="center">
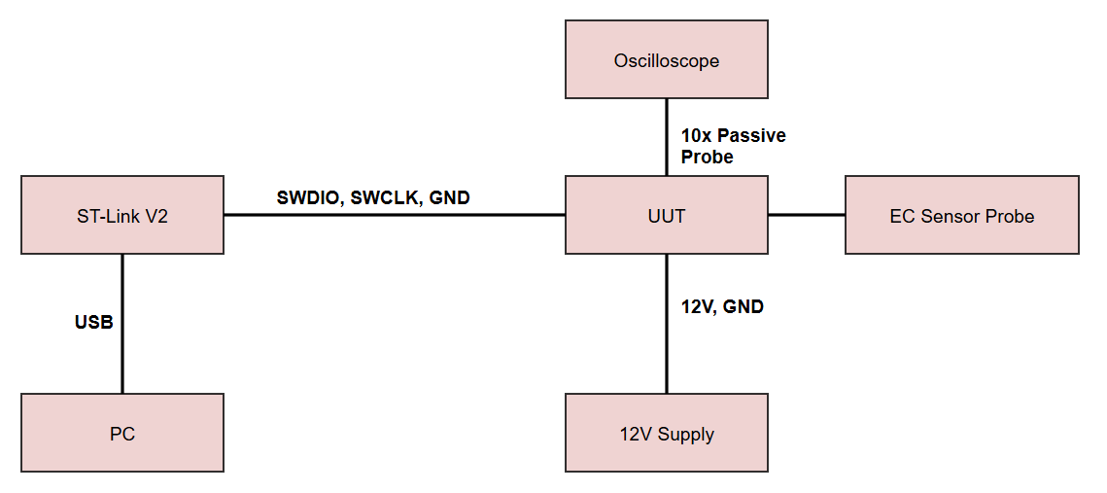
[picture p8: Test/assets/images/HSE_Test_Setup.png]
Setup
  
  <br>
  <em>Figure 2: HSE clock testing setup</em>
</p>

<p>&nbsp;</p>

| Step # | Description | Success Criteria | P/F |
|---|---|---|-----|
| 1 | Configure pin 29 as the MCO output for the HSE crystal oscillator and setup a basic LED blink program with a 1Hz frequency | Pin 29 is no longer configured as the RS485 enable signal and instead is configured as MCO Output for the HSE oscillator |  |
| 2 | Connect the oscilloscope probe to the pin 29 on the STM32F108C8T6 IC1 | Probe is connected to pin 29 with appropriate ground reference |  |
| 3 | Connect ST-Link SWCLK, SWDIO, and GND pins to the UUT on connector J2. Disconnect 3.3V pin | Board remains unpowered until 12V is applied |  |
| 4 | Connect the 12V Power Supply power and ground to connector J4 on the UUT | Power supply power and ground is physically connected to J4 pin 1 (P_IN) and pin 4 (GND) |  |
| 5 | Flash the board with the new code (use a release build, not debug build). | Release build is successfully flashed to the board with no errors |  |
| 6 | Set oscilloscope to 500mV/Div, trigger level to 1.5V. | Oscilloscope is setup with these settings |  |
| 7 | Measure the oscillator frequency | Oscillator frequency is 8MHz +- 1% |  |
| 8 | Observe LED D2 | LED D2 is blinking at a rate of 1 Hz |  |

### Notes

---

# 5. References

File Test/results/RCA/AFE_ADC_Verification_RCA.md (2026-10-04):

# AFE and ADC Verification Root Cause Analysis (RCA)
## AFE Failure During Hardware Bring-Up  
**Author:** Jairo Huaylinos
**Date:** 2026-09-21
**Board:** Custom STM32-Based TDS Sensor PCB  

---

## 1. Overview
During the AFE & ADC Verification stage of the TDS Sensor PCB HW bring-up, the AFE output voltage / ADC input voltage reading was measured to be -220mV while the EC sensor probe was submersed in room temperature tap water. Under normal operation, the AFE should never output a negative voltage. The AFE is intended to produce a voltage in the range of 0-3.3V.

This Root Cause Analysis uses a **Fishbone (Ishikawa) Methodology** to identify contributing factors across design, components, process, tools, and testing.

---
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

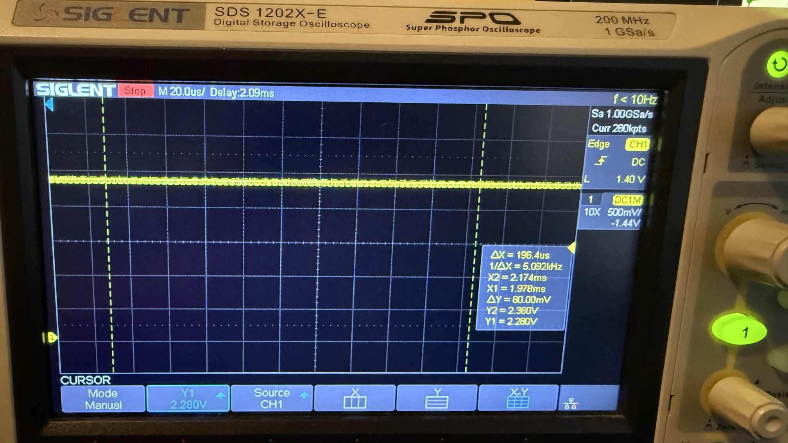
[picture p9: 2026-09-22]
Test/assets/images/ADC_Input_IC3_Replacement.jpg

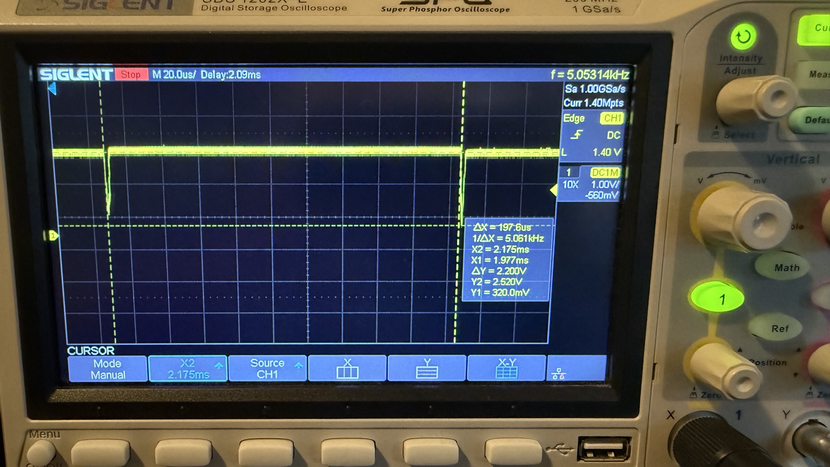
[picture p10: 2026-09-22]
Test/assets/images/Rectification_Output_IC3_Replacement.jpg

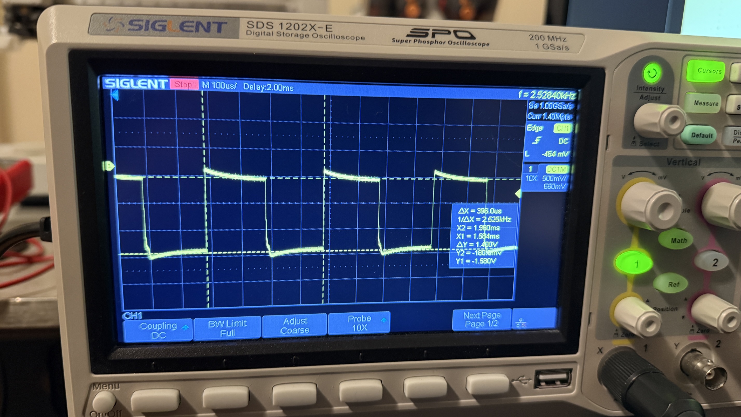
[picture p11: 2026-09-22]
Test/assets/images/OpAmpA_Output.jpg

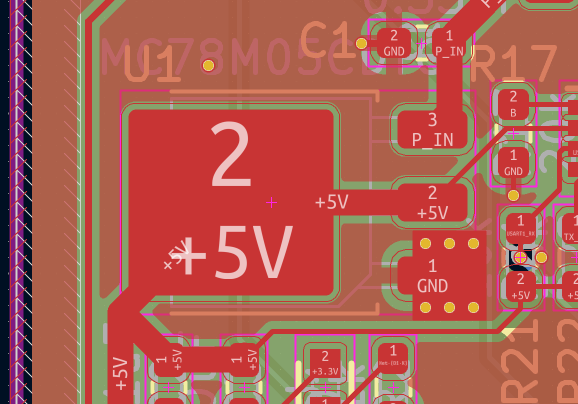
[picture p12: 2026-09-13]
Test/assets/images/5V_Regulator_PCB_footprint.png

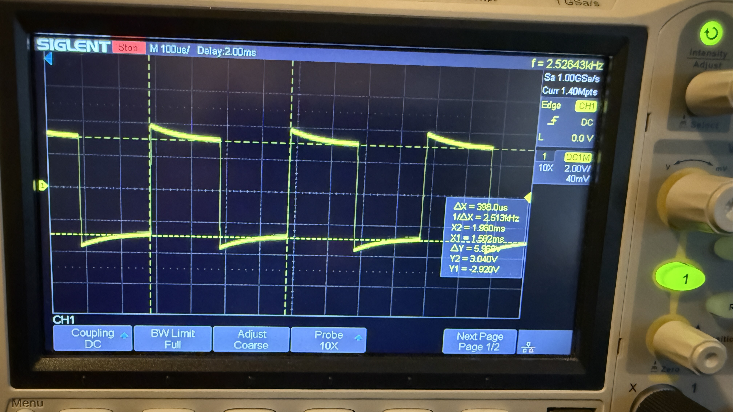
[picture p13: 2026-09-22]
Test/assets/images/Oscillator_2.5kHz.jpg

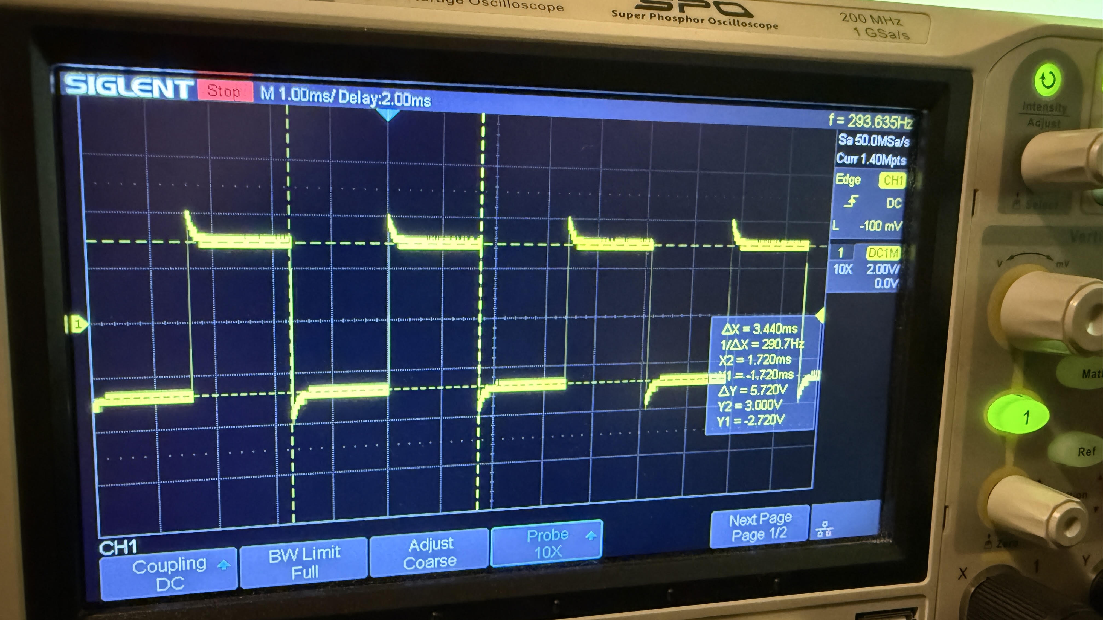
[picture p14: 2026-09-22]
Test/assets/images/Oscillator_290Hz.jpg

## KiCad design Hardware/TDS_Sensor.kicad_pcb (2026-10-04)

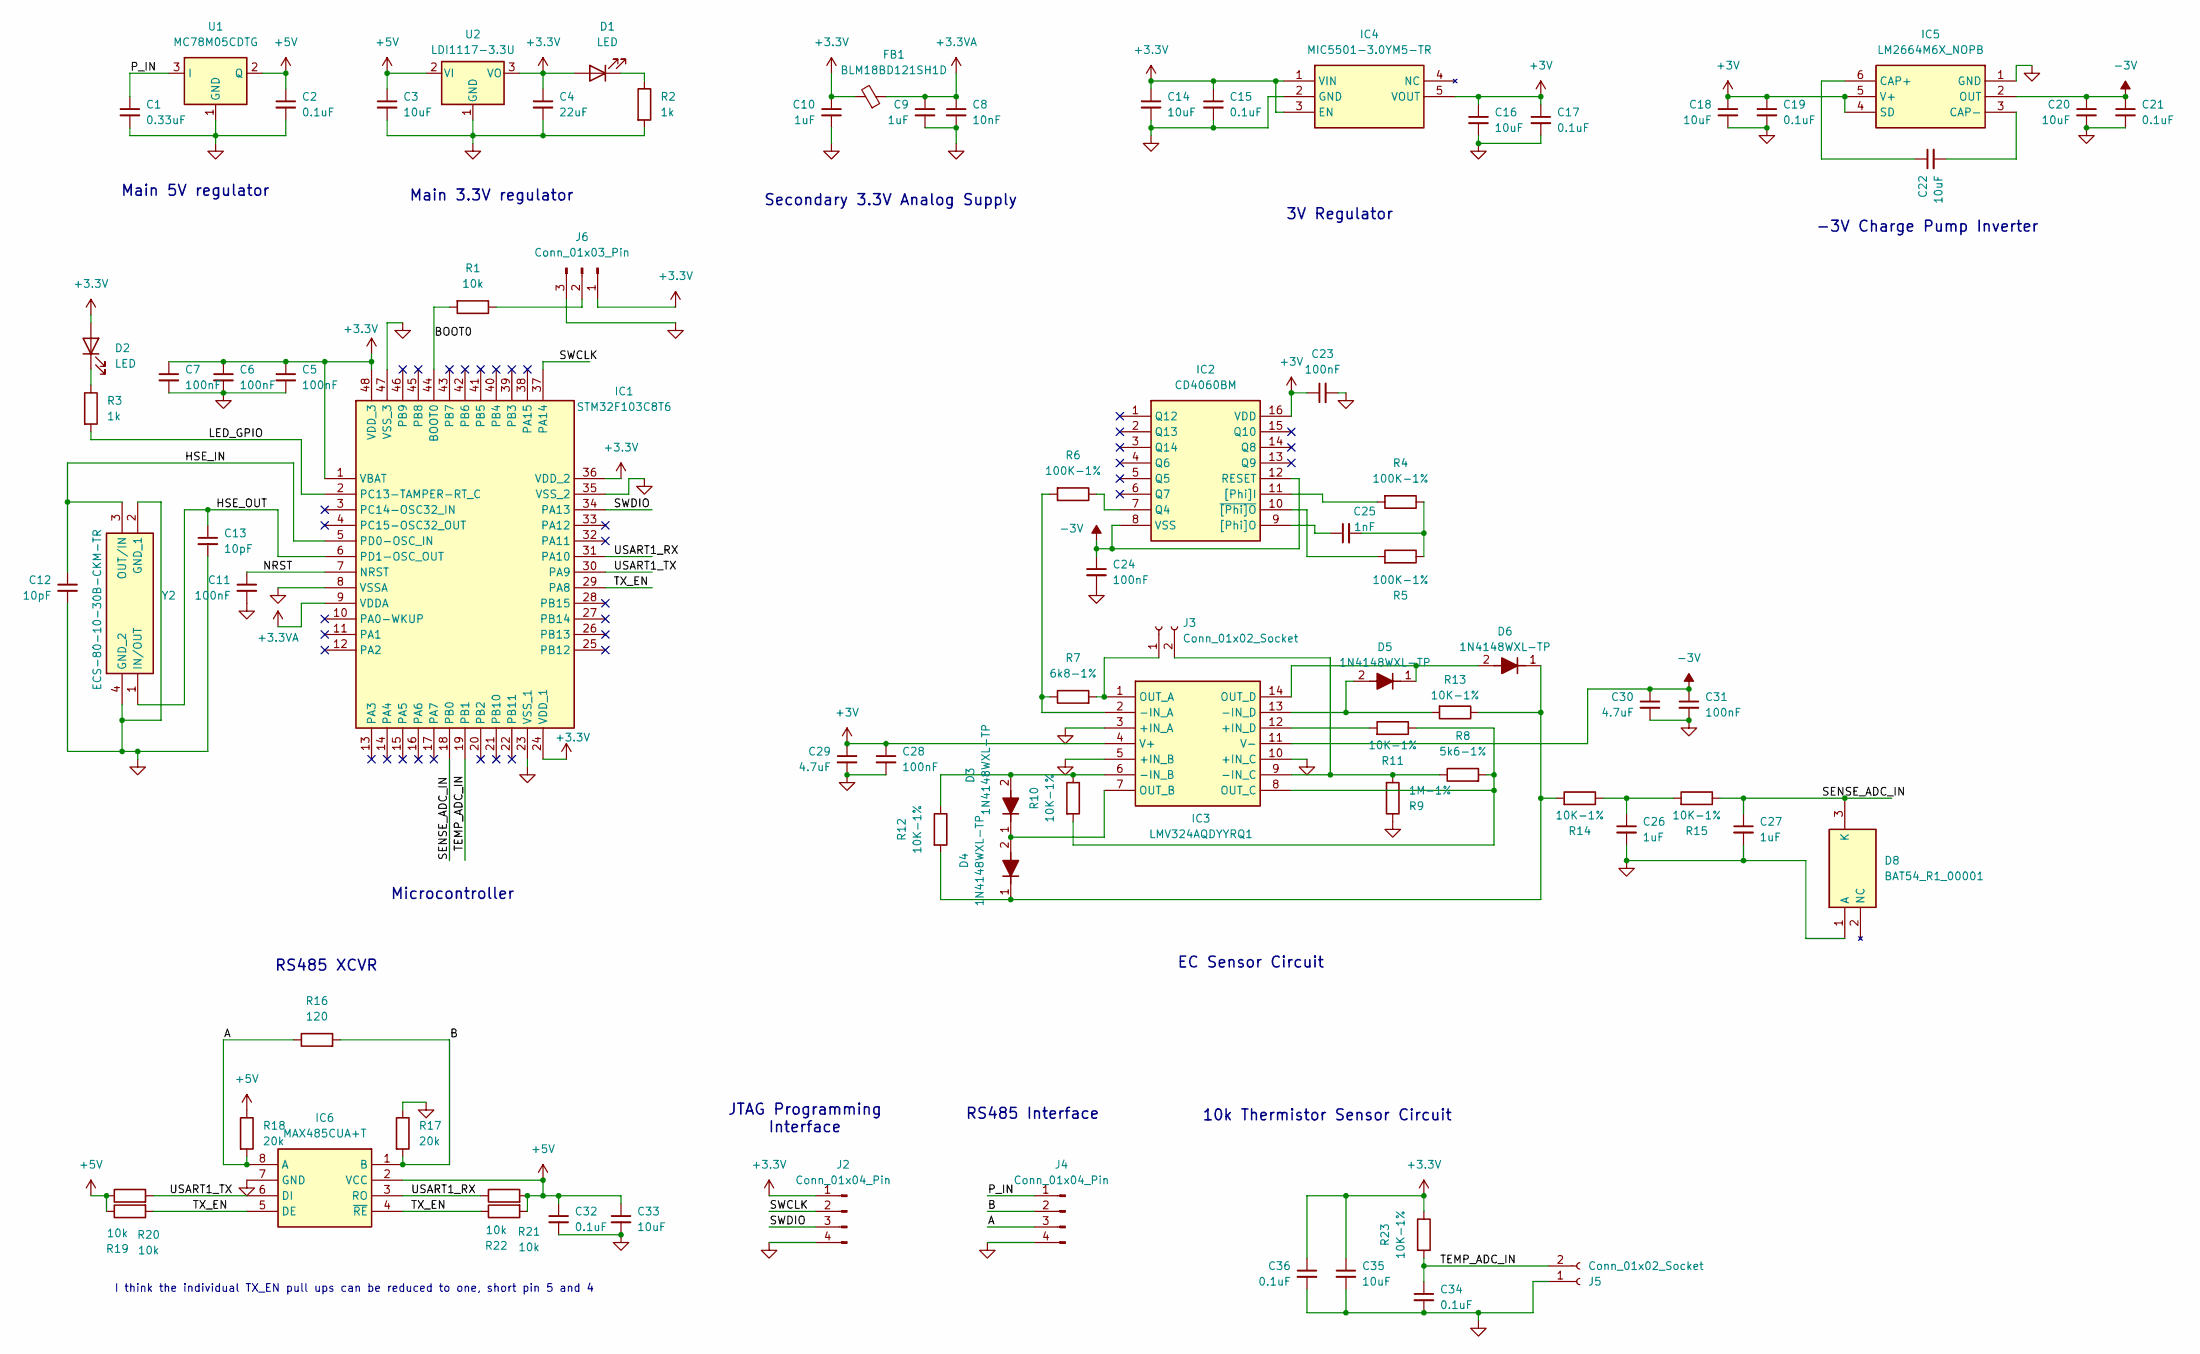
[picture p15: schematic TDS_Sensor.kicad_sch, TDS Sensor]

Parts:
C1: 0.33uF; C_0603_1608Metric_Pad1.08x0.95mm_HandSolder; Manufacturer_Part_Number 0603B334K160CT
C2, C15, C17, C19, C21, C32, C34, C36: 0.1uF; C_0603_1608Metric_Pad1.08x0.95mm_HandSolder; Manufacturer_Part_Number 885012206095
C3, C14, C16, C18, C20, C22, C33, C35: 10uF; C_0603_1608Metric_Pad1.08x0.95mm_HandSolder; Manufacturer_Part_Number CL10A106KQ8NNNL
C4: 22uF; C_0603_1608Metric_Pad1.08x0.95mm_HandSolder; Manufacturer_Part_Number GRM188R61A226ME15D
C5, C6, C7, C11, C23, C24, C28, C31: 100nF; C_0603_1608Metric_Pad1.08x0.95mm_HandSolder; Manufacturer_Part_Number 885012206095
C8: 10nF; C_0603_1608Metric_Pad1.08x0.95mm_HandSolder; Manufacturer_Part_Number GRM188R72A103KA01J
C9, C10, C26, C27: 1uF; C_0603_1608Metric_Pad1.08x0.95mm_HandSolder; Manufacturer_Part_Number 0603B105K100CT
C12, C13: 10pF; C_0603_1608Metric_Pad1.08x0.95mm_HandSolder; Manufacturer_Part_Number 0603N100F500CT
C25: 1nF; C_0603_1608Metric_Pad1.08x0.95mm_HandSolder; Manufacturer_Part_Number CL10C102JB81PNC
C29, C30: 4.7uF; C_0603_1608Metric_Pad1.08x0.95mm_HandSolder; Manufacturer_Part_Number GRT188C80G475KE01D
D1, D2: LED; LEDC1608X90N; Manufacturer_Part_Number LTST-C190GKT
D3, D4, D5, D6: 1N4148WXL-TP; 1N4148WXLTP; Manufacturer_Part_Number 1N4148WXL-TP; Mouser Part Number 833-1N4148WXL-TP
D8: BAT54_R1_00001; SOT95P240X110-3N; Manufacturer_Part_Number BAT54_R1_00001; Mouser Part Number 241-BAT54_R1_00001
FB1: BLM18BD121SH1D; BLM18SP221SN1B; Manufacturer_Part_Number BLM18BD121SH1D
IC1: STM32F103C8T6; QFP50P900X900X160-48N; Manufacturer_Part_Number STM32F103C8T6; Mouser Part Number 511-STM32F103C8T6
IC2: CD4060BM; SOIC127P600X175-16N; Manufacturer_Part_Number CD4060BM; Mouser Part Number 595-CD4060BM
IC3: LMV324AQDYYRQ1; SOP50P326X110-14N; Manufacturer_Part_Number LMV324AQDYYRQ1; Mouser Part Number 595-LMV324AQDYYRQ1
IC4: MIC5501-3.0YM5-TR; SOT95P280X145-5N; Manufacturer_Part_Number MIC5501-3.0YM5-TR; Mouser Part Number 998-MIC5501-3.0YM5TR
IC5: LM2664M6X_NOPB; SOT95P280X145-6N; Manufacturer_Part_Number LM2664M6X/NOPB; Mouser Part Number 926-LM2664M6X/NOPB
IC6: MAX485CUA+T; SOP65P490X110-8N; Manufacturer_Part_Number MAX485CUA+T; Mouser Part Number 700-MAX485CUAT
J2: Conn_01x04_Pin; HDRRA4W66P0X254_1X4_1016X229X274P; Manufacturer_Part_Number 22-28-8040
J3, J5: Conn_01x02_Socket; HDRRA2W64P0X254_1X2_508X250X288P; Manufacturer_Part_Number PH1RB-02-UA
J4: Conn_01x04_Pin; Custom_Wire_Solder_Pad_4POS
J6: Conn_01x03_Pin; PinHeader_1x03_P2.00mm_Vertical
R1, R19, R20, R21, R22: 10k; R_0603_1608Metric_Pad0.98x0.95mm_HandSolder; Manufacturer_Part_Number RK73H1JTTDD1002F
R2, R3: 1k; R_0603_1608Metric_Pad0.98x0.95mm_HandSolder; Manufacturer_Part_Number CRGCQ0603F1K0
R4, R5, R6: 100K-1%; R_0603_1608Metric_Pad0.98x0.95mm_HandSolder; Manufacturer_Part_Number WR06X1003FTL
R7: 6k8-1%; R_0603_1608Metric_Pad0.98x0.95mm_HandSolder; Manufacturer_Part_Number CRG0603F6K8
R8: 5k6-1%; R_0603_1608Metric_Pad0.98x0.95mm_HandSolder; Manufacturer_Part_Number CRGH0603F5K6
R9: 1M-1%; R_0603_1608Metric_Pad0.98x0.95mm_HandSolder; Manufacturer_Part_Number CR0603-FX-1004ELF
R10, R11, R12, R13, R14, R15, R23: 10K-1%; R_0603_1608Metric_Pad0.98x0.95mm_HandSolder; Manufacturer_Part_Number RK73H1JTTDD1002F
R16: 120; R_0603_1608Metric_Pad0.98x0.95mm_HandSolder; Manufacturer_Part_Number RC0603FR-07120RL
R17, R18: 20k; R_0603_1608Metric_Pad0.98x0.95mm_HandSolder; Manufacturer_Part_Number RK73H1JTTDD2002F
U1: MC78M05CDTG; TO-252-3_TabPin2; Manufacturer_Part_Number MC78M05CDTG
U2: LDI1117-3.3U; SOT-89-3_Handsoldering; Manufacturer_Part_Number LDI1117-3.3U
Y2: ECS-80-10-30B-CKM-TR; ECS801030BCKMTR; Manufacturer_Part_Number ECS-80-10-30B-CKM-TR; Mouser Part Number 520-80-10-30B-CKM-TR

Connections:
+3.3V: C4.1, C5.1, C6.1, C7.1, C10.1, C14.1, C15.1, C35.1, C36.1, D1.2 (A), D2.2 (A), FB1.2, IC1.1 (VBAT), IC1.24 (VDD_1), IC1.36 (VDD_2), IC1.48 (VDD_3), IC4.1 (VIN), IC4.3 (EN), J2.1, J6.1, R23.1, U2.3 (VO)
+3.3VA: C8.1, C9.1, FB1.1, IC1.9 (VDDA)
+3V: C16.1, C17.1, C18.1, C19.1, C23.1, C28.1, C29.1, IC2.16 (VDD), IC3.4 (V+), IC4.5 (VOUT), IC5.4 (SD), IC5.5 (V+)
+5V: C2.1, C3.1, C32.1, C33.1, IC6.2 (VCC), R18.1, R19.1, R20.1, R21.2, R22.2, U1.2 (Q), U2.2 (VI)
-3V: C20.1, C21.1, C24.1, C30.1, C31.1, IC2.8 (VSS), IC2.12 (RESET), IC3.11 (V-), IC5.2 (OUT)
/A: IC6.8 (A), J4.3, R16.1, R18.2
/B: IC6.1 (B), J4.2, R16.2, R17.2
/BOOT0: IC1.44 (BOOT0), R1.2
/HSE_IN: C12.1, IC1.5 (PD0-OSC_IN), Y2.3 (OUT/IN)
/HSE_OUT: C13.1, IC1.6 (PD1-OSC_OUT), Y2.1 (IN/OUT)
/LED_GPIO: IC1.2 (PC13-TAMPER-RT_C), R3.2
/NRST: C11.1, IC1.7 (NRST)
/P_IN: C1.1, J4.1, U1.3 (I)
/SENSE_ADC_IN: C27.1, D8.3 (K), IC1.18 (PB0), R15.1
/SWCLK: IC1.37 (PA14), J2.2
/SWDIO: IC1.34 (PA13), J2.3
/TEMP_ADC_IN: C34.1, IC1.19 (PB1), J5.2, R23.2
/TX_EN: IC1.29 (PA8), IC6.4 (~RE), IC6.5 (DE), R19.2, R22.1
/USART1_RX: IC1.31 (PA10), IC6.3 (RO), R21.1
/USART1_TX: IC1.30 (PA9), IC6.6 (DI), R20.2
GND: C1.2, C2.2, C3.2, C4.2, C5.2, C6.2, C7.2, C8.2, C9.2, C10.2, C11.2, C12.2, C13.2, C14.2, C15.2, C16.2, C17.2, C18.2, C19.2, C20.2, C21.2, C23.2, C24.2, C26.2, C27.2, C28.2, C29.2, C30.2, C31.2, C32.2, C33.2, C34.2, C35.2, C36.2, D8.1 (A), IC1.8 (VSSA), IC1.23 (VSS_1), IC1.35 (VSS_2), IC1.47 (VSS_3), IC3.3 (+IN_A), IC3.5 (+IN_B), IC3.10 (+IN_C), IC4.2 (GND), IC5.1 (GND), IC6.7 (GND), J2.4, J4.4, J5.1, J6.3, R2.2, R9.1, R17.1, U1.1 (GND), U2.1 (GND), Y2.2 (GND_1), Y2.4 (GND_2)
unnamed: C25.2, R4.1, R5.1
unnamed: C26.1, R14.1, R15.2
unnamed: D1.1 (K), R2.1
unnamed: D2.1 (K), R3.1
unnamed: D3.2 (A), IC3.6 (-IN_B), R10.1, R12.1
unnamed: D3.1 (K), D4.2 (A), IC3.7 (OUT_B)
unnamed: D4.1 (K), D6.1 (K), R12.2, R13.1, R14.2
unnamed: D5.2 (A), IC3.13 (-IN_D), R13.2
unnamed: D5.1 (K), D6.2 (A), IC3.14 (OUT_D)
unnamed: IC2.7 (Q4), R6.1
unnamed: IC2.11 ([Phi]I), R4.2
unnamed: C25.1, IC2.9 ([Phi]O)
unnamed: IC2.10 (~[Phi]O), R5.2
unnamed: IC3.12 (+IN_D), R11.2
unnamed: IC3.2 (-IN_A), R6.2, R7.1
unnamed: IC3.9 (-IN_C), J3.2, R8.1, R9.2
unnamed: IC3.1 (OUT_A), J3.1, R7.2
unnamed: IC3.8 (OUT_C), R8.2, R10.2, R11.1
unnamed: C22.1, IC5.6 (CAP+)
unnamed: C22.2, IC5.3 (CAP-)
unnamed: J6.2, R1.1

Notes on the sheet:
10k Thermistor Sensor Circuit
Main 3.3V regulator
RS485 XCVR
Microcontroller
-3V Charge Pump Inverter
I think the individual TX_EN pull ups can be reduced to one, short pin 5 and 4
JTAG Programming Interface
Secondary 3.3V Analog Supply
3V Regulator
RS485 Interface
Main 5V regulator
EC Sensor Circuit

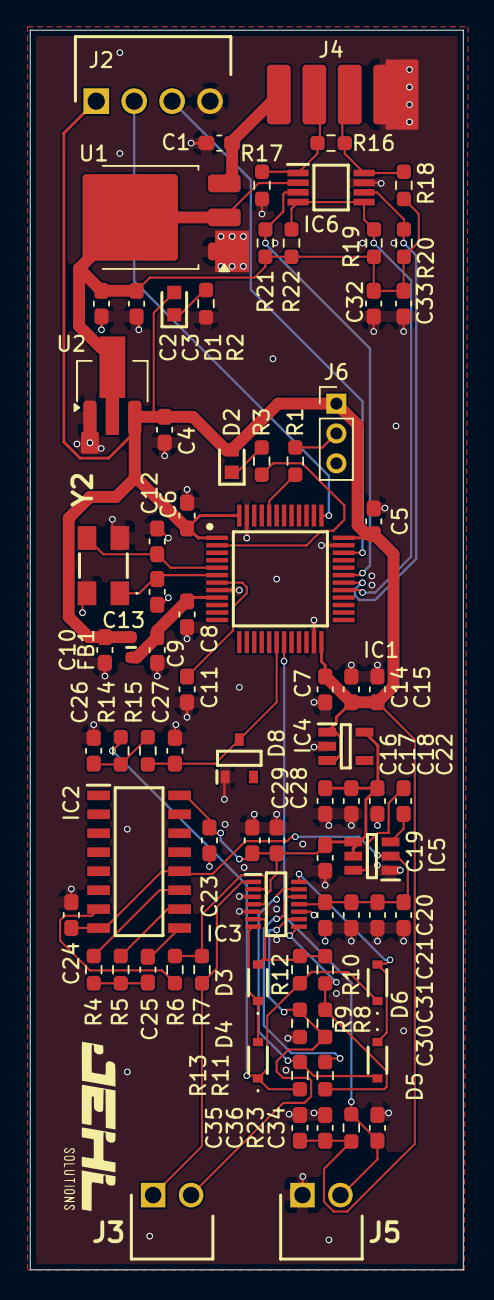
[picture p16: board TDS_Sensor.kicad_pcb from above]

Board: 4 copper layers, 29.0 x 83.0 mm, 81 parts (0 on the bottom side), 42 nets.

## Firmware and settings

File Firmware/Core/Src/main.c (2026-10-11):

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
/* Includes ------------------------------------------------------------------*/
#include "main.h"

/* USER CODE BEGIN Includes */
#include "string.h"
//#include "usbd_cdc_if.h"
#include "Modbus_RTU_Driver.h"
#include "modbus_slave.h"
/* USER CODE END Includes */

ADC_HandleTypeDef hadc1;

UART_HandleTypeDef huart1;

/* USER CODE BEGIN PV */
ModbusRTU_Driver rtu;

uint16_t sensor_reading;
float v_reading;
uint16_t v_estimate;
float v_estimate_f;
float tdsValue;
uint16_t tds;
char msg[50];
uint8_t tx_buffer[16];
uint8_t rx_buffer[16];

extern uint16_t g_mb_input_regs[MODBUS_NUM_INPUT_REGS];
/*
typedef struct
{
	uint16_t y; //last output
	float alpha; //alpha, smooting factor 0 < alpha < 1
} LPF;
*/
typedef struct
{
	uint16_t x; // state estimate
	float p; // estimate variance
	float r; // measurement variance
	float q; // process variance
}KalmanFilter;

/* USER CODE END PV */

void SystemClock_Config(void);
static void MX_GPIO_Init(void);
static void MX_ADC1_Init(void);
static void MX_USART1_UART_Init(void);
/* USER CODE BEGIN PFP */
/*
void LPF_Init(LPF *lpfilt, float alpha)
{
	lpfilt->y = 0;
	lpfilt->alpha = alpha;
}
uint16_t LPF_Update(LPF *lpfilt, uint16_t x)
{
	lpfilt->y = lpfilt->y + (uint16_t) (lpfilt->alpha*(x - lpfilt->y) + 0.5f);
	return lpfilt->y;
}*/

//Kalman Filter
void Kalman_Init(KalmanFilter *kalman, float x0, float p0, float r, float q)
{
	kalman->x = (uint16_t)x0; // state estimate
	kalman->p = p0; // estimate variance
	kalman->r = r; // measurement noise
	kalman->q = q;// process noise
}

uint16_t Kalman_Update(KalmanFilter *kalman, uint16_t z_uint16)
{
	float z = (float)z_uint16;
	float x_prior = (float)kalman->x;
	float p_prior = kalman->p + kalman->q;

	// Kalman Gain
	float Kn = p_prior / (p_prior + kalman->r);
	float x_post = x_prior + Kn*(z - x_prior);
	kalman->p = (1-Kn)*p_prior;
	kalman->x = (uint16_t)x_post;
	return kalman->x;
}

//code to print a float to character buffer
/*
void PrintFloat(char *buff, float x, uint16_t decimals)
{
	flaot scale = 1;
	for(int i = 1; i<=decimals; i++) scale *= 10.0f;
	uint16_t whole = (uint16_t)x;
	uint16_t frac = (uint16_t) x*scale;

}*/
/* USER CODE END PFP */

/**
  * @brief  The application entry point.
  * @retval int
  */
int main(void)
{

  /* MCU Configuration--------------------------------------------------------*/

  /* Reset of all peripherals, Initializes the Flash interface and the Systick. */
  HAL_Init();

  /* USER CODE BEGIN Init */
  /*
  LPF filter1;
  float alpha = 0.0625f;
  LPF_Init(&filter1, alpha);
  */
  g_mb_input_regs[0] = 0;

  KalmanFilter kf1;
  float x0 = 15000.0f;
  float p0 = 1e-4f;
  float r = 1e-3f;
  float q = 1e-4f;

  Kalman_Init(&kf1, x0, p0, r, q);

  Modbus_Slave_Init();

  /* USER CODE END Init */

  /* Configure the system clock */
  SystemClock_Config();

  /* Initialize all configured peripherals */
  MX_GPIO_Init();
  MX_ADC1_Init();
  MX_USART1_UART_Init();
  /* USER CODE BEGIN 2 */
  HAL_ADC_Start(&hadc1);
  ModbusRTU_Init(&rtu,
  		  	  	 &huart1,
  				 GPIOA, //enable port
  				 GPIO_PIN_8, //enable pin
  				 Modbus_Slave_OnFrame);
  /* USER CODE END 2 */

  /* Infinite loop */
  /* USER CODE BEGIN WHILE */
  while (1)
  {
    /* USER CODE END WHILE */

    /* USER CODE BEGIN 3 */
	  HAL_ADC_PollForConversion(&hadc1, HAL_MAX_DELAY);
	  ModbusRTU_Poll(&rtu); //poll modbus
	  sensor_reading = HAL_ADC_GetValue(&hadc1);
	  //v_reading = sensor_reading*8; // Voltage in 10^-4 V reactivate this line
	  // v_estimate = LPF_Update(&filter1, v_reading);
	  v_reading = sensor_reading*8.105f;
	  /*v_estimate = Kalman_Update(&kf1, v_reading);
	  v_estimate_f = (float) v_estimate;
	  v_estimate_f = v_estimate_f/10000.0f;
	  tdsValue = (133.42f * v_estimate_f * v_estimate_f * v_estimate_f - 255.86f * v_estimate_f * v_estimate_f + 857.39f * v_estimate_f) * 0.5f; //convert voltage value to tds value
	  tds = (uint16_t)(tdsValue*100.0f);*/
	  g_mb_input_regs[0] = (uint16_t) v_reading;

	  //tds = (uint16_t) tdsValue;
	  /* this is for usb transmission:
	  sprintf(msg, "read: %hu.%03hu V, Est: %hu.%03hu V, ppm: %hu.%02hu\r\n", (uint16_t)(v_reading/10000), (uint16_t)(v_reading%10000), (uint16_t)(v_estimate/10000), (uint16_t)(v_estimate%10000), (uint16_t)(tds/100), (uint16_t)(tds%100));
	  CDC_Transmit_FS((uint8_t *)msg, strlen(msg));
	  */
	  HAL_GPIO_WritePin(GPIOC, GPIO_PIN_13, 1);
	  HAL_Delay(250);
	  HAL_GPIO_WritePin(GPIOC, GPIO_PIN_13, 0);
	  HAL_Delay(250);
  }
  /* USER CODE END 3 */
}

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


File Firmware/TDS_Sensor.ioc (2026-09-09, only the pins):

Mcu.UserName=STM32F103C8Tx
PA10.Signal=USART1_RX
PA13.Signal=SYS_JTMS-SWDIO
PA14.Signal=SYS_JTCK-SWCLK
PA8.GPIO_Label=TX_EN
PA8.Signal=GPIO_Output
PA9.Signal=USART1_TX
PB0.Signal=ADCx_IN8
PC13-TAMPER-RTC.Signal=GPIO_Output
PD0-OSC_IN.Signal=RCC_OSC_IN
PD1-OSC_OUT.Signal=RCC_OSC_OUT

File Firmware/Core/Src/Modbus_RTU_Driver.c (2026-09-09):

/*
 * Modbus_RTU_Driver.c
 *
 *  Created on: Dec 17, 2025
 *      Author: jairo
 */

// Modbus_RTU_Driver.c
#include "Modbus_RTU_Driver.h"

void ModbusRTU_Init(ModbusRTU_Driver *d, UART_HandleTypeDef *huart,
                    GPIO_TypeDef *DE_Port, uint16_t DE_Pin,
                    Modbus_FrameCallback cb) {
    d->huart = huart;
    d->DE_Port = DE_Port;
    d->DE_Pin = DE_Pin;
    d->rx_len = 0;
    d->frame_pending = 0;
    d->on_frame = cb;

    HAL_GPIO_WritePin(DE_Port, DE_Pin, GPIO_PIN_RESET); // RX mode
    __HAL_UART_ENABLE_IT(huart, UART_IT_RXNE); // enable interrupt for received byte
    __HAL_UART_ENABLE_IT(huart, UART_IT_IDLE); // IDLE line marks frame boundary. triggered after 1 character time silence.
    __HAL_UART_ENABLE_IT(huart, UART_IT_ERR); // enable interrupt for error detection
}

HAL_StatusTypeDef ModbusRTU_Send(ModbusRTU_Driver *d, const uint8_t *p, uint16_t len) {
    HAL_GPIO_WritePin(d->DE_Port, d->DE_Pin, GPIO_PIN_SET); // TX
    HAL_StatusTypeDef st = HAL_UART_Transmit(d->huart, p, len, 100); // in OG copilot code, p was casted to (uint8_t *) b/c assumed this function didn't define p as const
    if (st != HAL_OK) {
        HAL_GPIO_WritePin(d->DE_Port, d->DE_Pin, GPIO_PIN_RESET); // back to RX
        return st;
    }
    while (__HAL_UART_GET_FLAG(d->huart, UART_FLAG_TC) == RESET) {}
    HAL_GPIO_WritePin(d->DE_Port, d->DE_Pin, GPIO_PIN_RESET); // RX
    return HAL_OK;
}

// Call from ISR when RXNE set
void ModbusRTU_OnRxByte(ModbusRTU_Driver *d, uint8_t byte) {
    if (d->rx_len < sizeof(d->rx_buf)) {
        d->rx_buf[d->rx_len++] = byte;
    } else {
        // overflow: drop frame
        d->rx_len = 0; // reset rx_len. but we never reset the rx_buf. rx_buff will just get overwritten starting at index 0 and increasing.
    }
}

// Call from ISR when IDLE flag set
void ModbusRTU_OnIdle(ModbusRTU_Driver *d) {
    if (d->rx_len > 0) { // check that we have been receiving data, if we now get idle, that means end of frame.
        d->frame_pending = 1;
        // IDLE triggers at multiple times when bus is silent not just at 1 char time after end of frame
        // thus we have to check that a frame was in progress
    }
}

// Call from main loop; dispatch completed frames
void ModbusRTU_Poll(ModbusRTU_Driver *d) {
    if (d->frame_pending) { // if end of frame detected and ready for next frame
        d->frame_pending = 0; // reset, we already know end of frame and are taking action in the following
        if (d->on_frame) d->on_frame(d->rx_buf, d->rx_len); // if(d->on_frame) checks if there is a callback function defined. calls the the callback handler function we defined at Init (Modbus_FrameCallback cb)
        // I assume the callback function will restart the UART_ENABLE_IT() functions
        d->rx_len = 0; // reset buffer len so that next frame starts filling buffer at index 0.
    }
}

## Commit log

2026-09-09 Initial commit of KiCad Project with protected step file
    [TDS_Sensor.kicad_pcb, TDS_Sensor.kicad_sch, TDS_Sensor.step]
2026-09-09 Initial Stm32 commite with clean byte for byte formatting rules
    [TDS_Sensor Debug.cfg]
2026-09-10 Folder Re-organization. Create Hardware folder for KiCad files. Create folder for test documentation. Rename .gitattributes.txt to .gitattributes. Update .gitignore.
    [TDS_Sensor.kicad_pcb, TDS_Sensor.kicad_sch, TDS_Sensor.step]
2026-09-18 Updated AFE/ADC Verification RCA
2026-10-04 Test Plan Updates
    [TDS_Sensor.kicad_pcb]
2026-11-01 PCB noisy trace re-route
2026-11-07 PCB Revisions - New Rev A
2026-11-07 Rev A PCB Updates In Progress
2026-11-07 rename PCB/Schem PDFs to Rev-
2026-11-08 PCB Silkscreen updates
2026-11-13 PCB Rev 2 updates

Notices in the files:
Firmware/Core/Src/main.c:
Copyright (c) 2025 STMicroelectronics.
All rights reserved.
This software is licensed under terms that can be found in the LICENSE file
